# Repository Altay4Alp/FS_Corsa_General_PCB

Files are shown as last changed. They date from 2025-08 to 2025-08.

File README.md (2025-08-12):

# Formula Student Corsa Node Board
This is a pcb design for a car we made called Corsa. Corsa is made to create experiences for team to make better cars for formula student races. In this pcb design it is aimed to control the car and getting datas from the car. 

The board designed to use: 
- 3 temprature sensor
- 2 servo motor
- 1 dc motor
- 1 gps sensor
- 1 acceleration sensor
- 1 stop light
- 1 can bus line

That list can be used as a default by just programming. But it is designed to be able to use all of the potential of STM32 blue pill. Sensors and other things can be added as wanted.

pcb_front

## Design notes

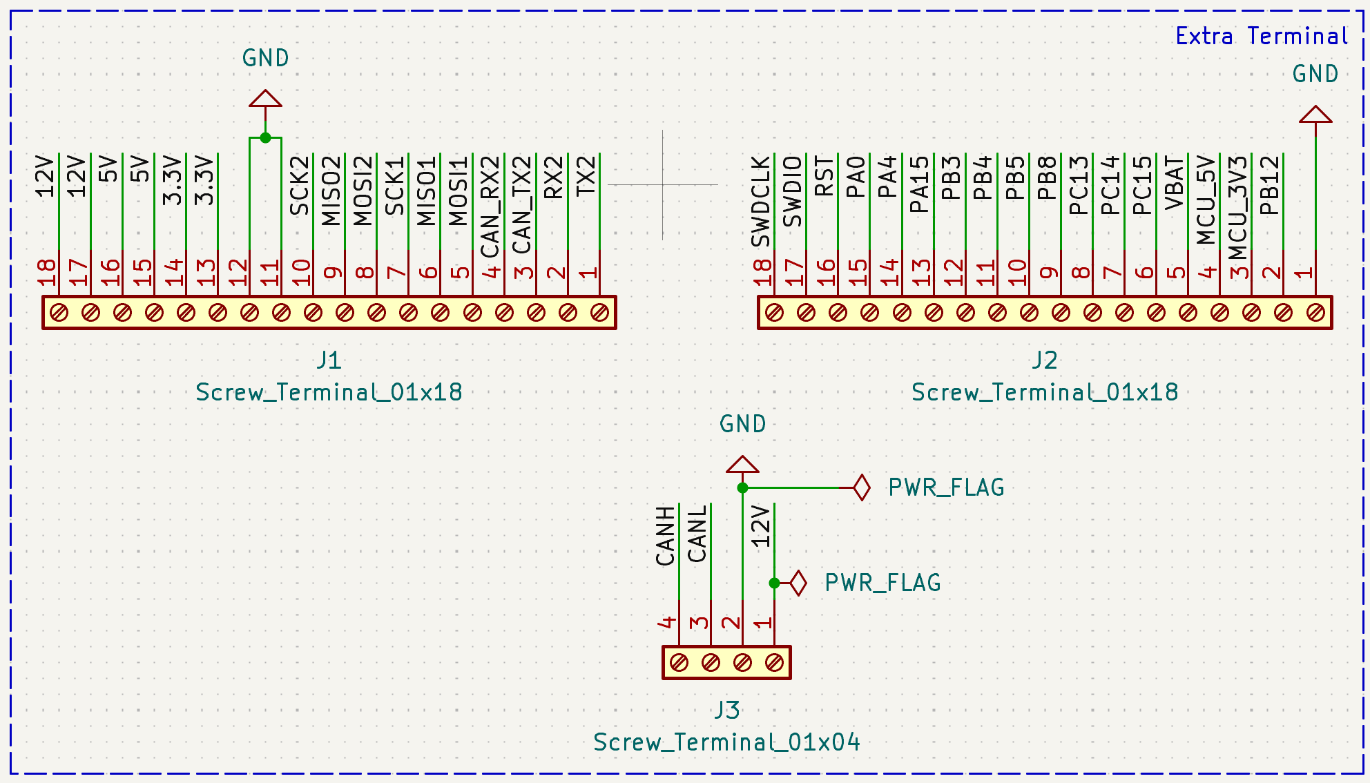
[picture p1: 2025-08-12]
Images/term_sch.png

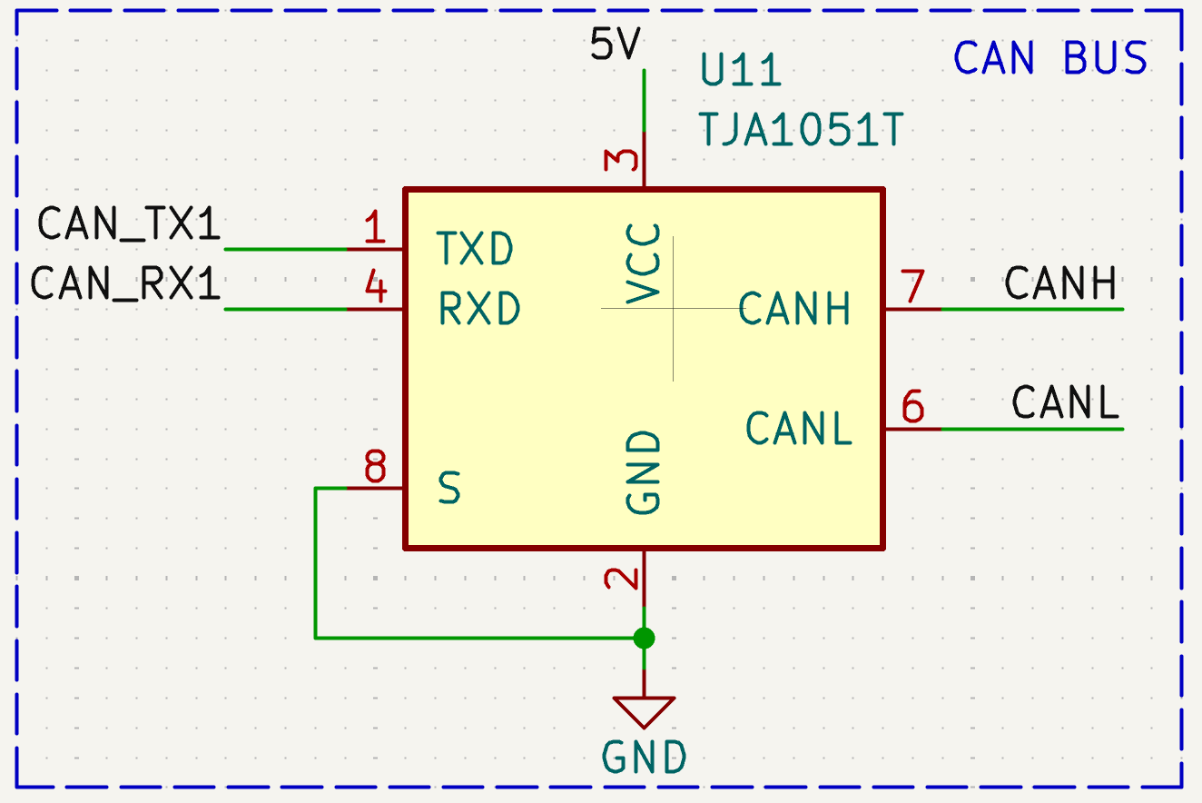
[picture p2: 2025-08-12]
Images/Canbus_sch.png

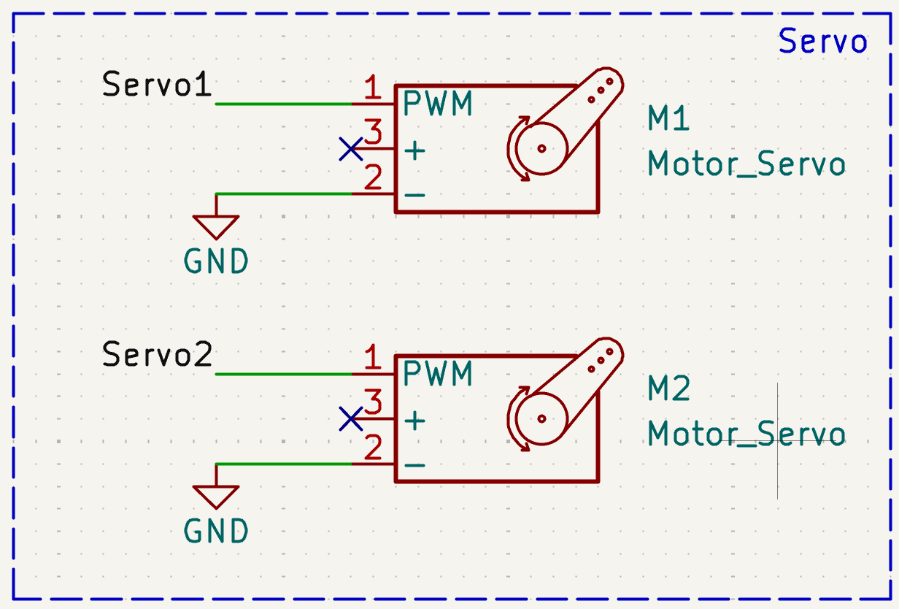
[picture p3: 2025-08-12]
Images/servo_sch.png

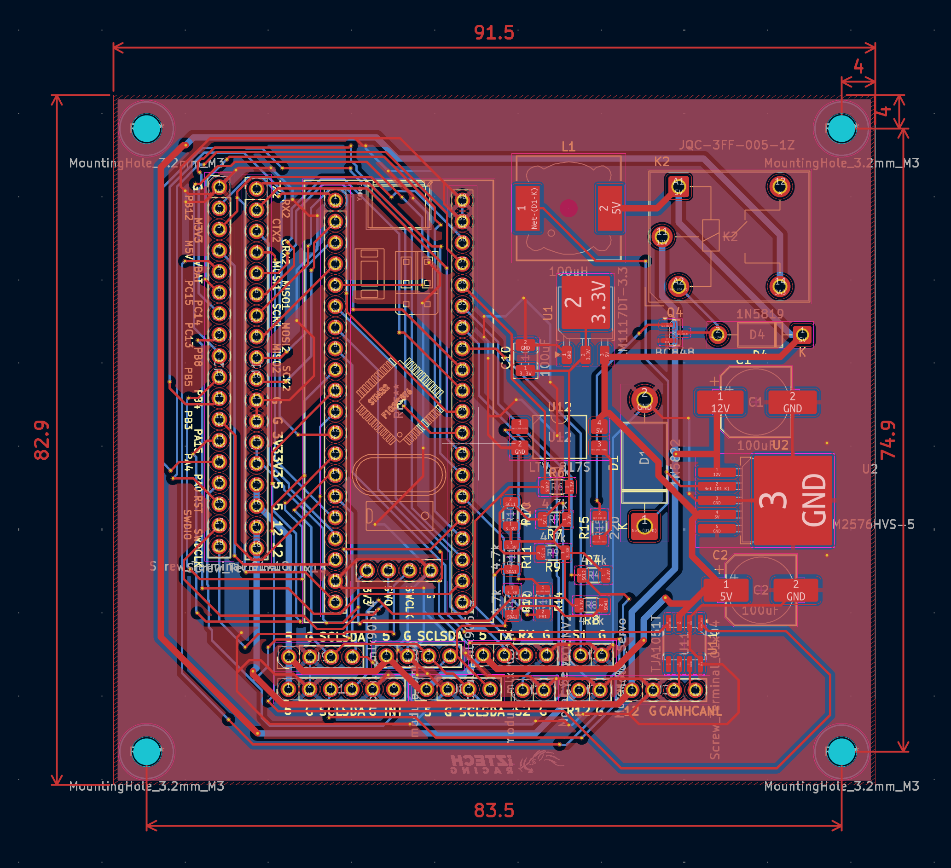
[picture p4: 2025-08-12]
Images/pcb_traces.png

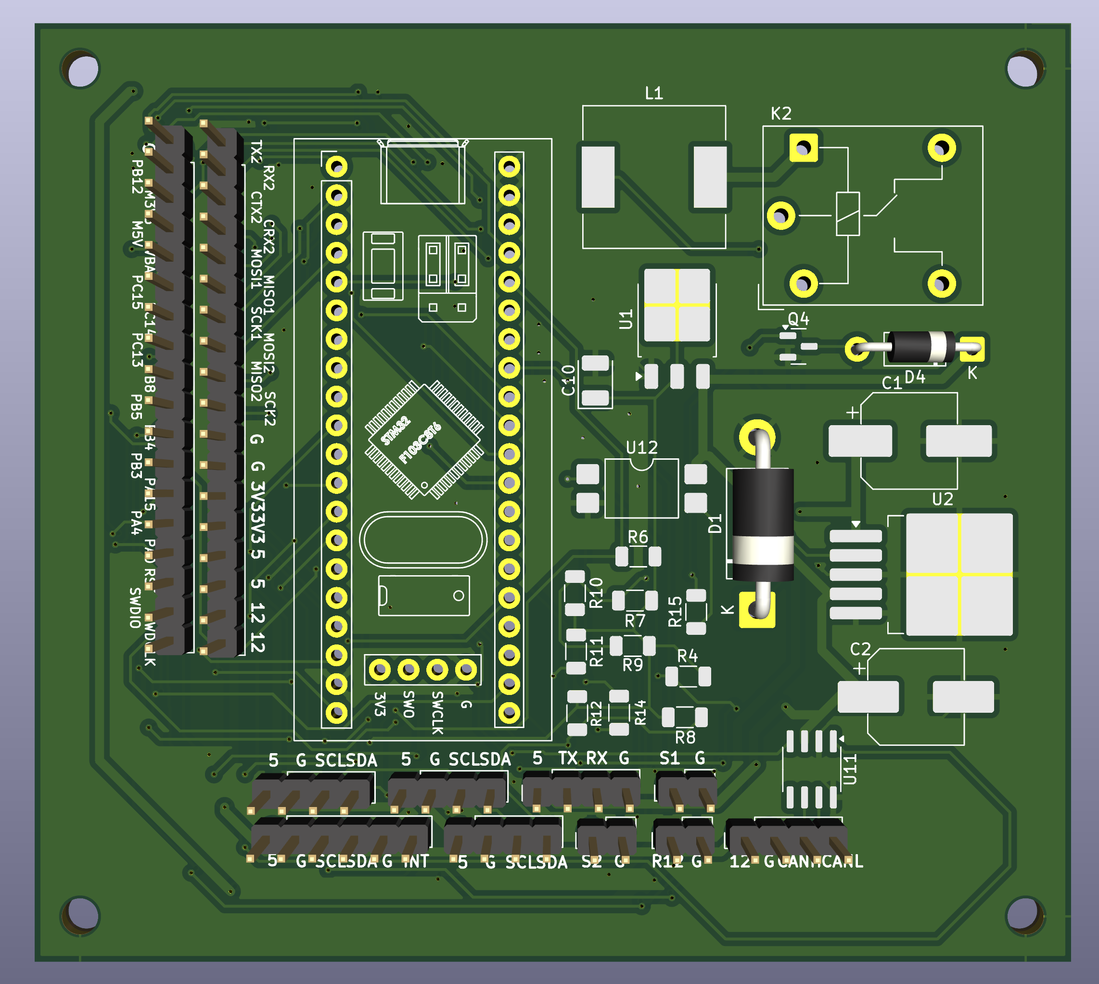
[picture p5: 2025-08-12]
Images/pcb_front.png

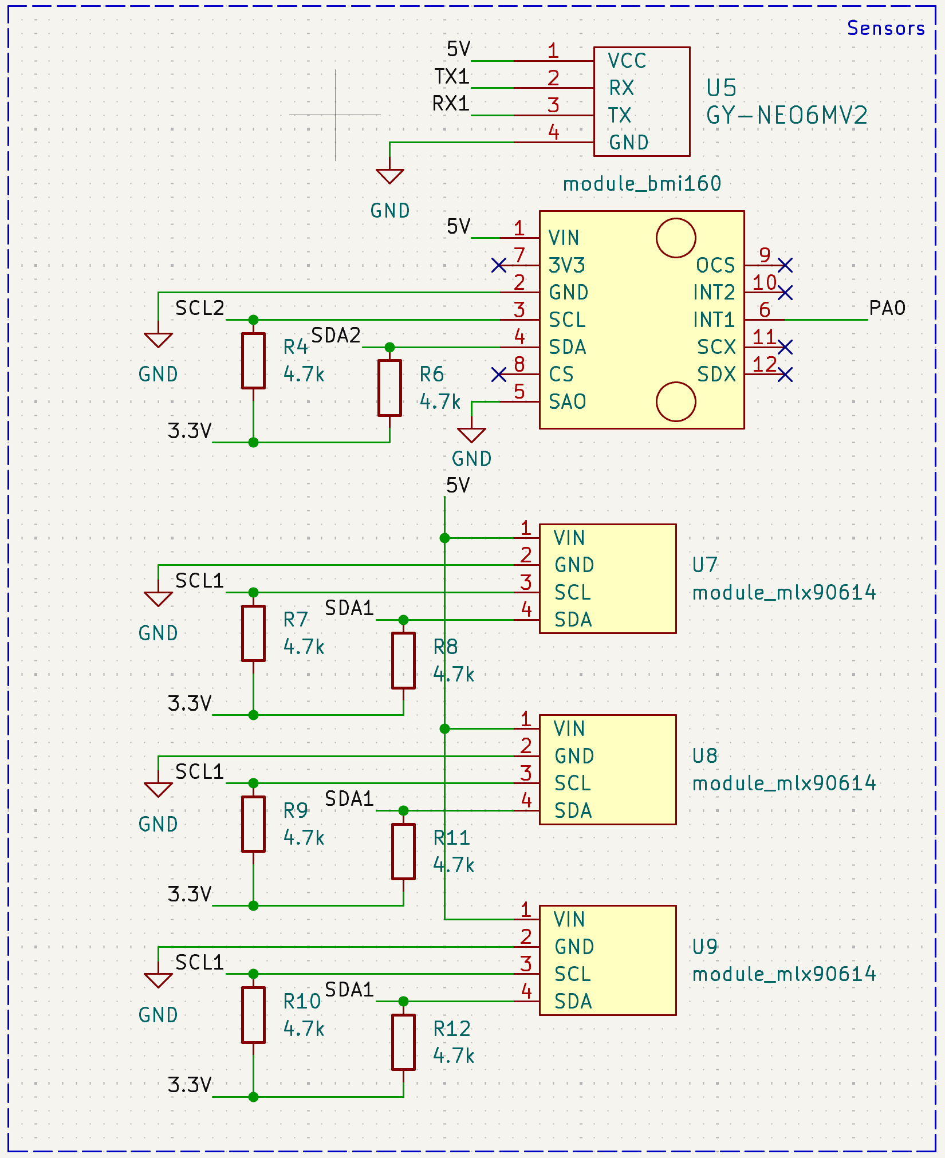
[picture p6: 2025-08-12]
Images/sensor_sch.png

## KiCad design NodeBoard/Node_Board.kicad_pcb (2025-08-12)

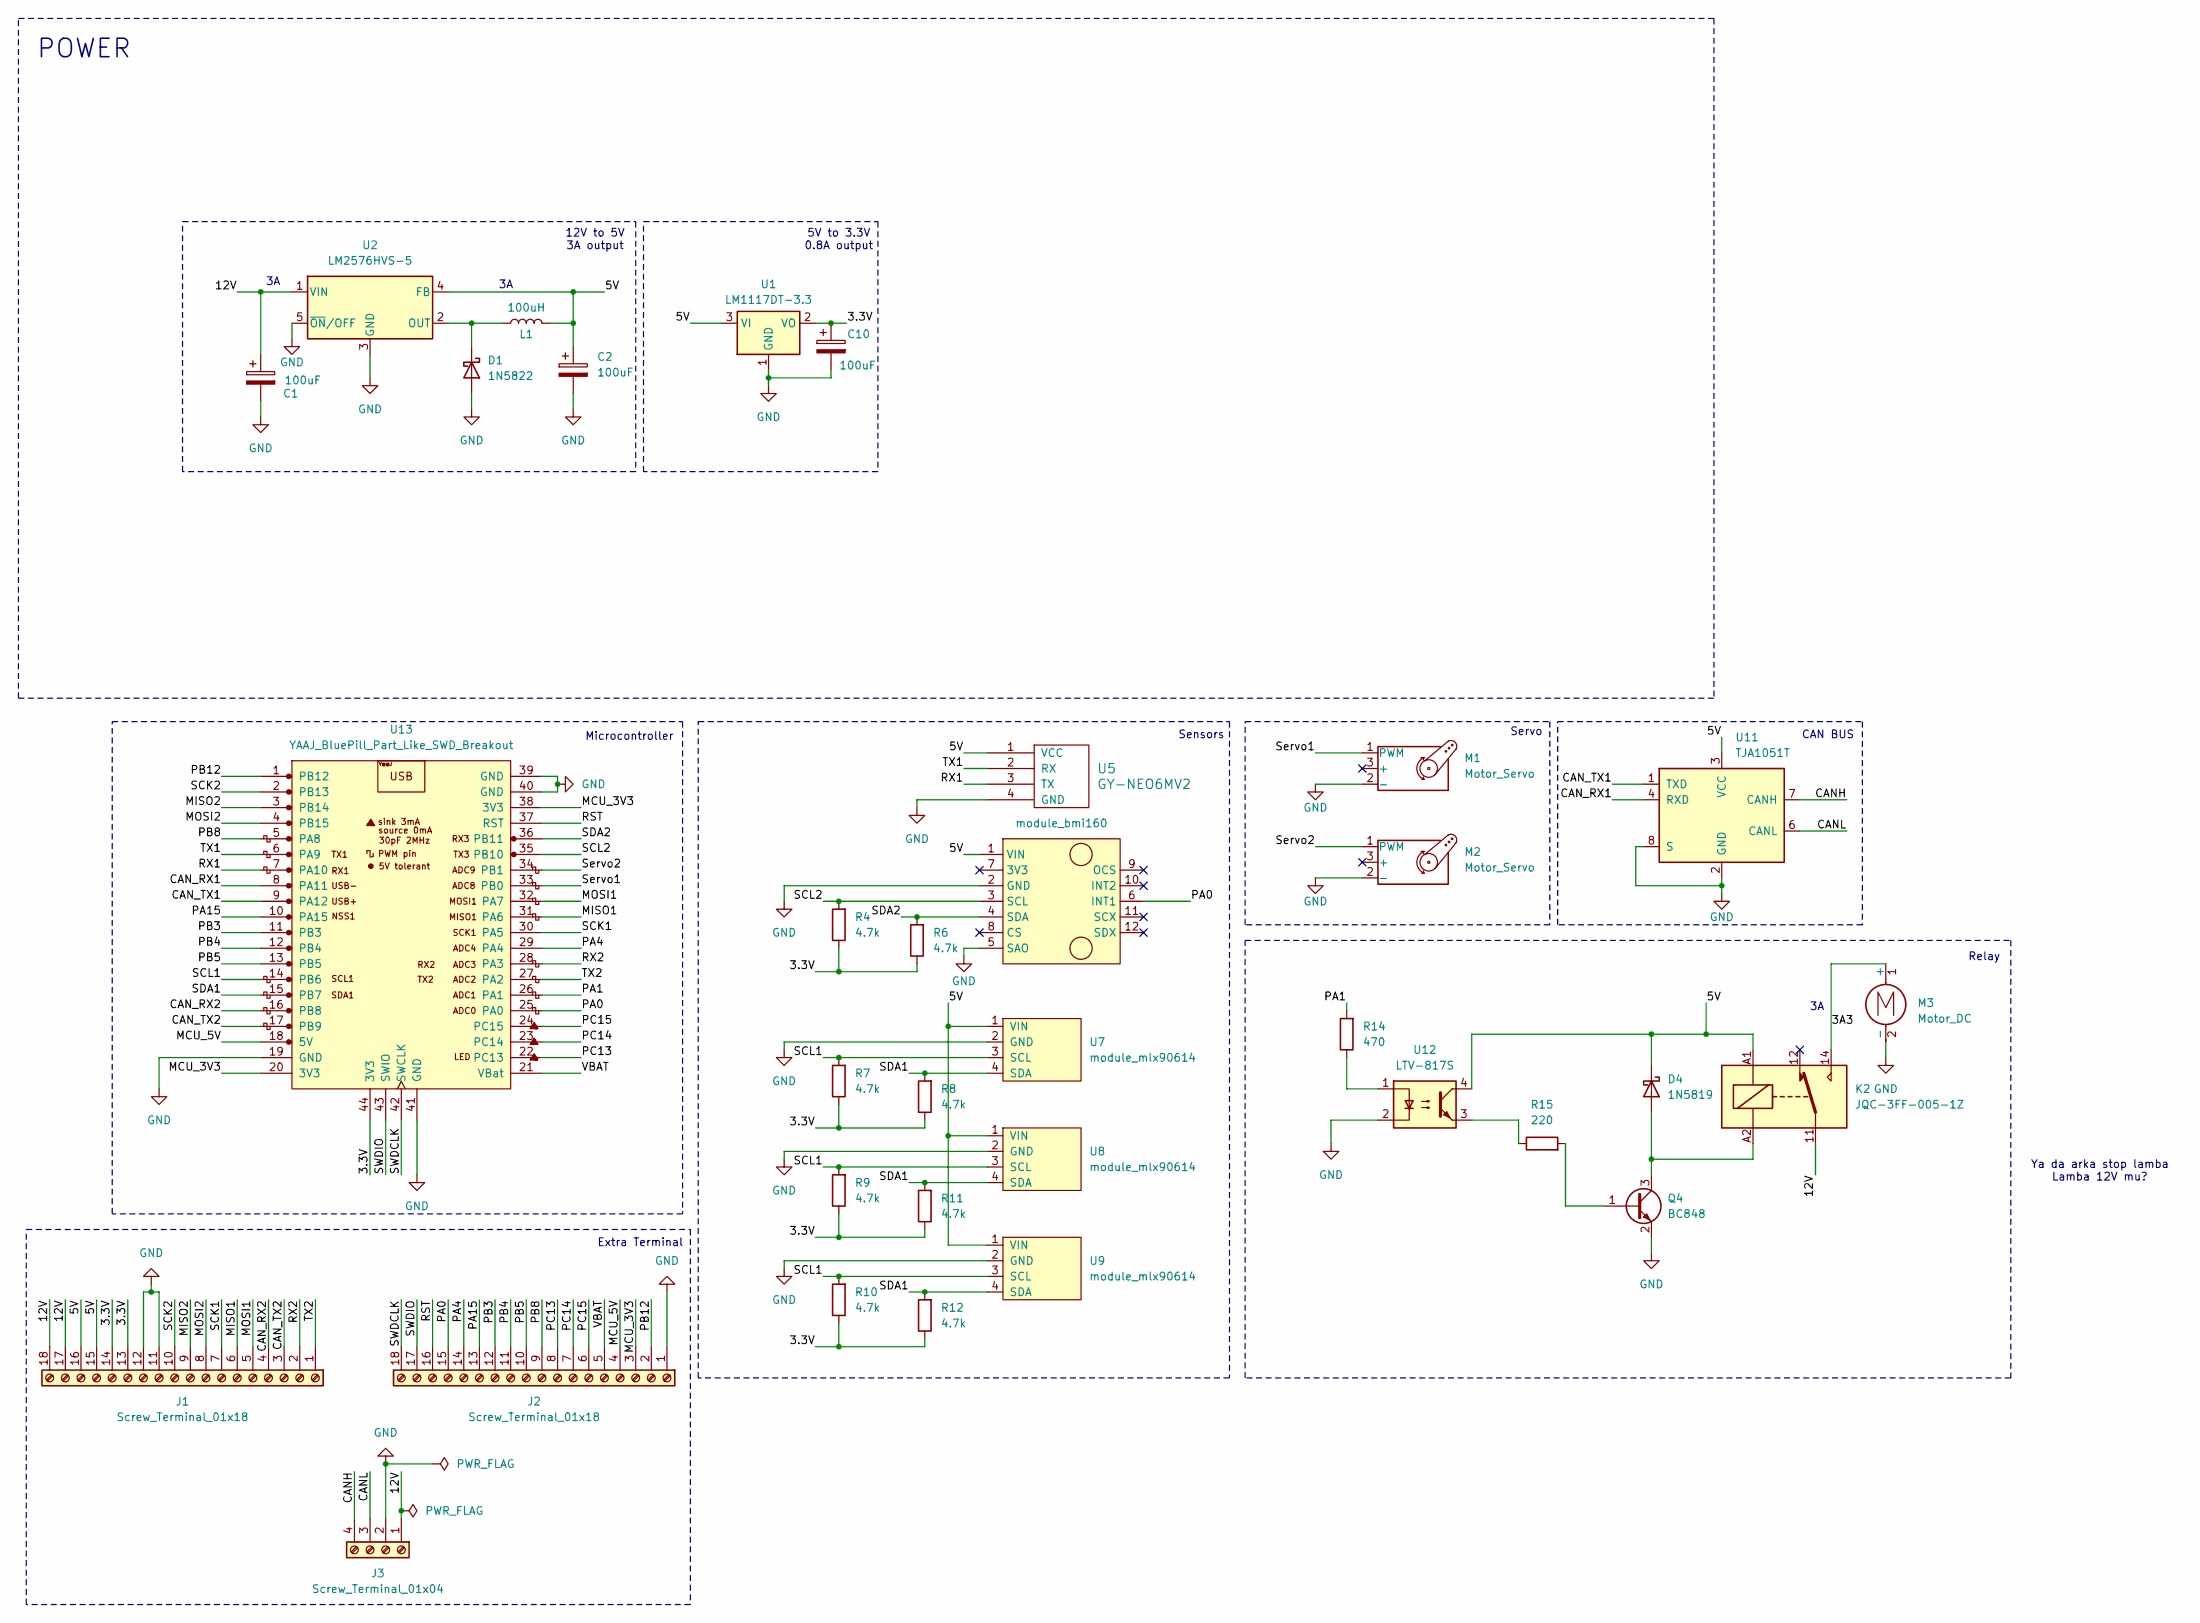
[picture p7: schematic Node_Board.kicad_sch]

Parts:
C1, C2: 100uF; CP_Elec_8x10
C10: 100uF; CP_EIA-3528-21_Kemet-B
D1: 1N5822; D_DO-201AD_P15.24mm_Horizontal
D4: 1N5819; D_DO-41_SOD81_P10.16mm_Horizontal
J1, J2: Screw_Terminal_01x18; PinHeader_1x18_P2.54mm_Vertical
J3: Screw_Terminal_01x04; PinHeader_1x04_P2.54mm_Vertical
K2: JQC-3FF-005-1Z; Relay_SPDT_Hongfa_JQC-3FF_0XX-1Z
L1: 100uH; L_12x12mm_H8mm
M1, M2: Motor_Servo; PinHeader_1x02_P2.54mm_Vertical
M3: Motor_DC; PinHeader_1x02_P2.54mm_Vertical
Q4: BC848; SOT-23
R4, R6, R7, R8, R9, R10, R11, R12: 4.7k; R_1206_3216Metric
R14: 470; R_1206_3216Metric
R15: 220; R_1206_3216Metric
U1: LM1117DT-3.3; TO-252-3_TabPin2
U2: LM2576HVS-5; TO-263-5_TabPin3
U5: GY-NEO6MV2; PinHeader_1x04_P2.54mm_Vertical
U7, U8, U9: module_mlx90614; PinHeader_1x04_P2.54mm_Vertical
U10: module_bmi160; PinHeader_1x06_P2.54mm_Vertical
U11: TJA1051T; SOIC-8_3.9x4.9mm_P1.27mm
U12: LTV-817S; SMDIP-4_W9.53mm
U13: YAAJ_BluePill_Part_Like_SWD_Breakout; YAAJ_BluePill_SWD_1

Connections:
/3.3V: C10.1, J1.13, J1.14, R4.1, R6.1, R7.1, R8.1, R9.1, R10.1, R11.1, R12.1, U1.2 (VO), U13.44 (3V3)
/3A3: K2.14, M3.1 (+)
/5V: C2.1, D4.1 (K), J1.15, J1.16, K2.A1, L1.2, U1.3 (VI), U2.4 (FB), U5.1 (VCC), U7.1 (VIN), U8.1 (VIN), U9.1 (VIN), U10.1 (VIN), U11.3 (VCC), U12.4
/12V: C1.1, J1.17, J1.18, J3.1, K2.11, U2.1 (VIN)
/CANH: J3.4, U11.7 (CANH)
/CANL: J3.3, U11.6 (CANL)
/CAN_RX1: U11.4 (RXD), U13.8 (PA11)
/CAN_RX2: J1.4, U13.16 (PB8)
/CAN_TX1: U11.1 (TXD), U13.9 (PA12)
/CAN_TX2: J1.3, U13.17 (PB9)
/MCU_3V3: J2.3, U13.20 (3V3), U13.38 (3V3)
/MCU_5V: J2.4, U13.18 (5V)
/MISO1: J1.6, U13.31 (PA6)
/MISO2: J1.9, U13.3 (PB14)
/MOSI1: J1.5, U13.32 (PA7)
/MOSI2: J1.8, U13.4 (PB15)
/PA0: J2.15, U10.6 (INT1), U13.25 (PA0)
/PA1: R14.2, U13.26 (PA1)
/PA4: J2.14, U13.29 (PA4)
/PA15: J2.13, U13.10 (PA15)
/PB3: J2.12, U13.11 (PB3)
/PB4: J2.11, U13.12 (PB4)
/PB5: J2.10, U13.13 (PB5)
/PB8: J2.9, U13.5 (PA8)
/PB12: J2.2, U13.1 (PB12)
/PC13: J2.8, U13.22 (PC13)
/PC14: J2.7, U13.23 (PC14)
/PC15: J2.6, U13.24 (PC15)
/RST: J2.16, U13.37 (RST)
/RX1: U5.3 (TX), U13.7 (PA10)
/RX2: J1.2, U13.28 (PA3)
/SCK1: J1.7, U13.30 (PA5)
/SCK2: J1.10, U13.2 (PB13)
/SCL1: R7.2, R9.2, R10.2, U7.3 (SCL), U8.3 (SCL), U9.3 (SCL), U13.14 (PB6)
/SCL2: R4.2, U10.3 (SCL), U13.35 (PB10)
/SDA1: R8.2, R11.2, R12.2, U7.4 (SDA), U8.4 (SDA), U9.4 (SDA), U13.15 (PB7)
/SDA2: R6.2, U10.4 (SDA), U13.36 (PB11)
/SWDCLK: J2.18, U13.42 (SWCLK)
/SWDIO: J2.17, U13.43 (SWIO)
/Servo1: M1.1 (PWM), U13.33 (PB0)
/Servo2: M2.1 (PWM), U13.34 (PB1)
/TX1: U5.2 (RX), U13.6 (PA9)
/TX2: J1.1, U13.27 (PA2)
/VBAT: J2.5, U13.21 (VBat)
GND: C1.2, C2.2, C10.2, D1.2 (A), J1.11, J1.12, J2.1, J3.2, M1.2 (-), M2.2 (-), M3.2 (-), Q4.2 (E), U1.1 (GND), U2.3 (GND), U2.5 (~ON/OFF), U5.4 (GND), U7.2 (GND), U8.2 (GND), U9.2 (GND), U10.2 (GND), U10.5 (SAO), U11.2 (GND), U11.8 (S), U12.2, U13.19 (GND), U13.39 (GND), U13.40 (GND), U13.41 (GND)
unnamed: D1.1 (K), L1.1, U2.2 (OUT)
unnamed: D4.2 (A), K2.A2, Q4.3 (C)
unnamed: Q4.1 (B), R15.2
unnamed: R14.1, U12.1
unnamed: R15.1, U12.3

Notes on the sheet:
Sensors
5V to 3.3V 0.8A output
POWER
Ya da arka stop lamba Lamba 12V mu?
Servo
Relay
CAN BUS
Extra Terminal
12V to 5V 3A output
Microcontroller

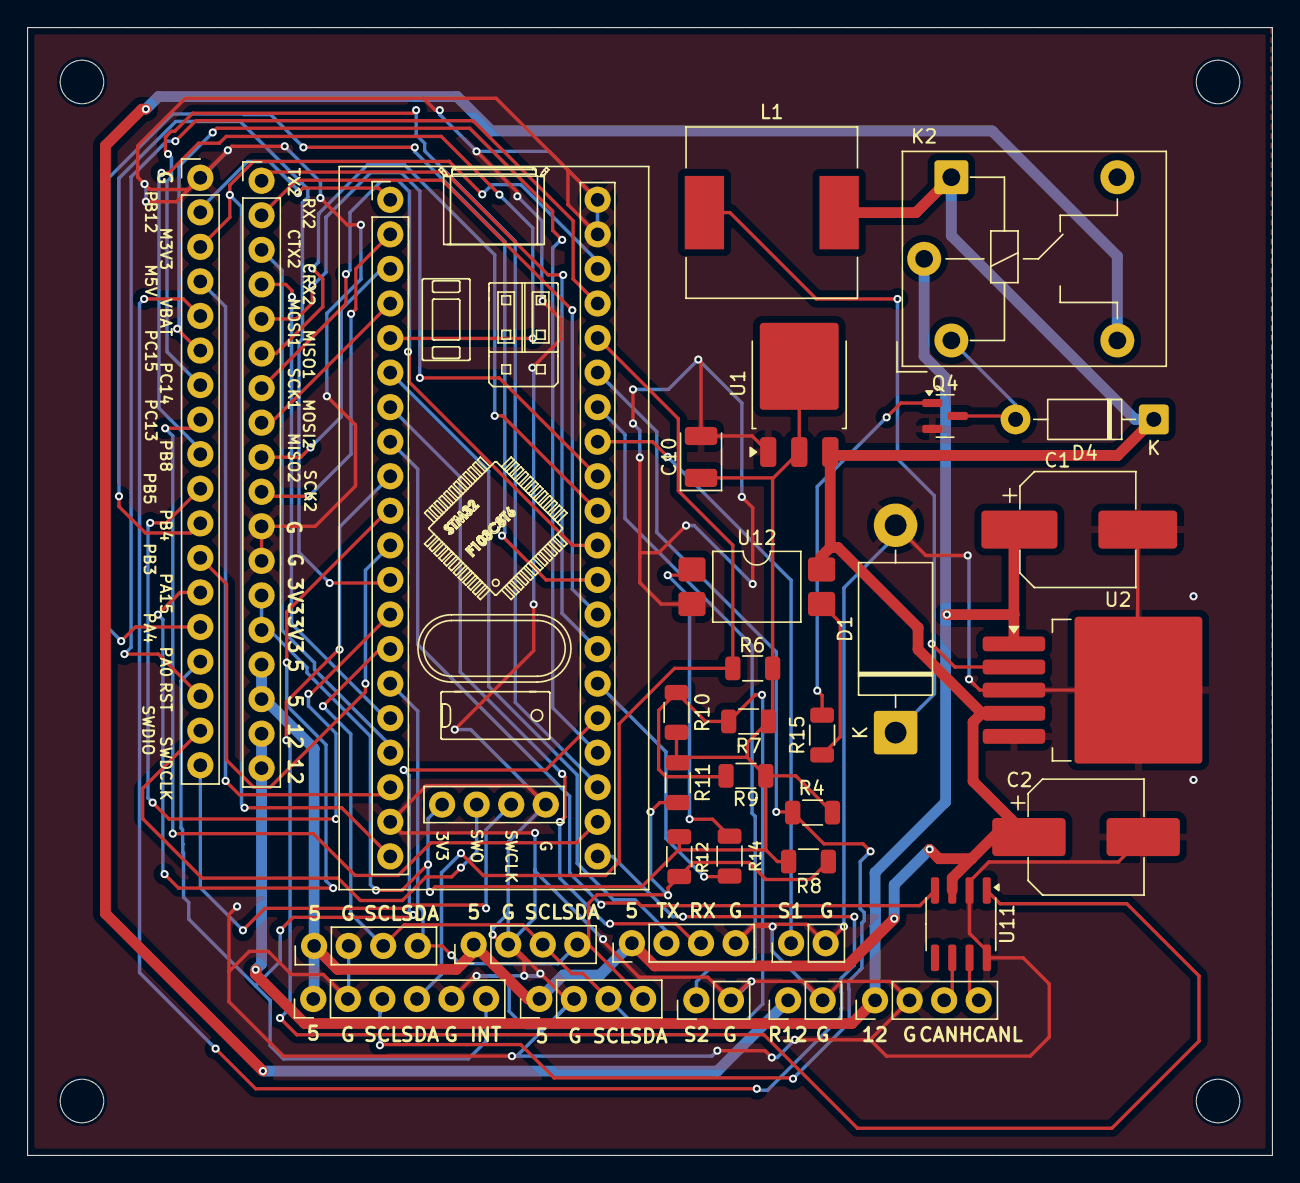
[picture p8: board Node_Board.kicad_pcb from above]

Board: 2 copper layers, 91.5 x 82.9 mm, 34 parts (0 on the bottom side), 50 nets.
